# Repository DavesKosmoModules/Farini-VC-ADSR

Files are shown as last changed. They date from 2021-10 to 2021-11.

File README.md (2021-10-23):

# Farini-VC-ADSR

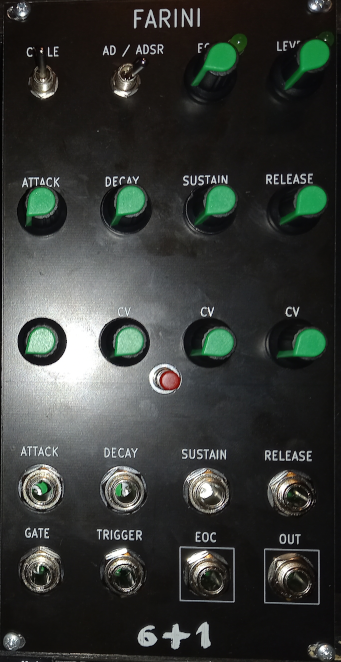
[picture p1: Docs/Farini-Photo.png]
Farini Photo


Voltage controlled AD / ADSR

- Envelope generator switchable between ADSR & AD
- Loopable
- End Of Cycle output
- Output can be inverted for ducking

- When in AD mode use the trigger input
- When in ADSR mode, use the gate input to start envelope, the trigger input will retigger the attach phase
- When in cycle mode use no inputs

 Contained are schematics & gerber files for pcb fabrication of both electrical and front panel. This is sutiable for entry level however a basic level of electronics, soldering, fault finding, and some basic tools are required.

 [Schematic](/Docs/Farini-Schematic.pdf)
 
 [BOM](Docs/Farini-BOM.pdf)

 If you wish to edit in ki-cad the following dependencies are required, however the component values will need tidying on the PCB as I use a forked version with no values.
 
  https://github.com/holmesrichards/Kosmo_panel
  
  https://github.com/holmesrichards/aoKicad

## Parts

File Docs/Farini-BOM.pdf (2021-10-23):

Id | Designator | Package | Quantity | Designation

1

| RV2,RV1,RV3,RV4,RV5,RV7,
| RV8,RV9,RV10 | Potentiometer_Alpha_RD901F‐40‐
| | 00D_Single_Vertical_CircularHoles_centered | | 9 100k

2

R45,R21,R3,R4,R5,R6,R8,R9
,R13,R14,R15,R16,R17,R18,
R19,R20,R22,R23,R26,R27,
R30,R31,R34,R37,R38,R39,
R41,R43,R46,R47,R48 | R_Axial_DIN0207_L6.3mm_D2.5mm_P10.16mm_Horizontal | 31 100k
3 R25,R32,R35 | R_Axial_DIN0207_L6.3mm_D2.5mm_P10.16mm_Horizontal | 3 10k
4 R1,R10,R11 | R_Axial_DIN0207_L6.3mm_D2.5mm_P10.16mm_Horizontal | 3 6k2
5 C1,C2 | CP_Radial_D6.3mm_P2.50mm | 2 10uF
6 C3,C4,C5,C6,C7,C8,C12,C13 C_Disc_D3.0mm_W1.6mm_P2.50mm | 8 0.1uF
7 C9 | C_Disc_D3.0mm_W1.6mm_P2.50mm | 1 0.001uF
8 C10 | C_Disc_D3.0mm_W1.6mm_P2.50mm | 1 0.01uF
9 C11 | C_Disc_D3.0mm_W1.6mm_P2.50mm | 1 0.03uF
10 D1,D5 | D_DO‐41_SOD81_P10.16mm_Horizontal | 2 1N5817

11

D2,D3,D4,D6,D7,D10,D11,D
12,D13 | D_DO‐35_SOD27_P7.62mm_Horizontal | 9 1N4148
12 D8,D9 | LED_D5.0mm | 2 LED
13 J1 | Power_Header | 1 Synth_power_2x5
14 J2 | PinHeader_1x10_P2.54mm_Vertical | 1 Conn_01x10_Male
15 Q1,Q2 | TO‐92_Inline_Wide | 2 2N3904
16 R2,R12,R24 | R_Axial_DIN0207_L6.3mm_D2.5mm_P10.16mm_Horizontal | 3 47k
17 R7,R33 | R_Axial_DIN0207_L6.3mm_D2.5mm_P10.16mm_Horizontal | 2 200k
18 R28,R42 | R_Axial_DIN0207_L6.3mm_D2.5mm_P10.16mm_Horizontal | 2 1k
19 R29 | R_Axial_DIN0207_L6.3mm_D2.5mm_P10.16mm_Horizontal | 1 30k
20 R36 | R_Axial_DIN0207_L6.3mm_D2.5mm_P10.16mm_Horizontal | 1 link
21 R40 | R_Axial_DIN0207_L6.3mm_D2.5mm_P10.16mm_Horizontal | 1 51k
22 R44 | R_Axial_DIN0207_L6.3mm_D2.5mm_P10.16mm_Horizontal | 1 470
23 RV6 | Potentiometer_Alpha_RD901F‐40‐
| 00D_Single_Vertical_CircularHoles_centered | 1 10k
24 SW1 | SPDT‐toggle‐switch‐1M‐series | 1 SW_SPDT
25 SW2 | DPDT‐toggle‐switch‐1M‐seriesx | 1 SW_DPDT_x2
26 SW3 | Push_button_A‐5050 | 1 SW_Push
27 U1,U2,U3 | DIP‐14_W7.62mm_Socket_LongPads | 3 TL074
28 U4 | DIP‐16_W7.62mm_Socket_LongPads | 1 AS3310
29 U5 | DIP‐8_W7.62mm_Socket_LongPads | 1 TL072

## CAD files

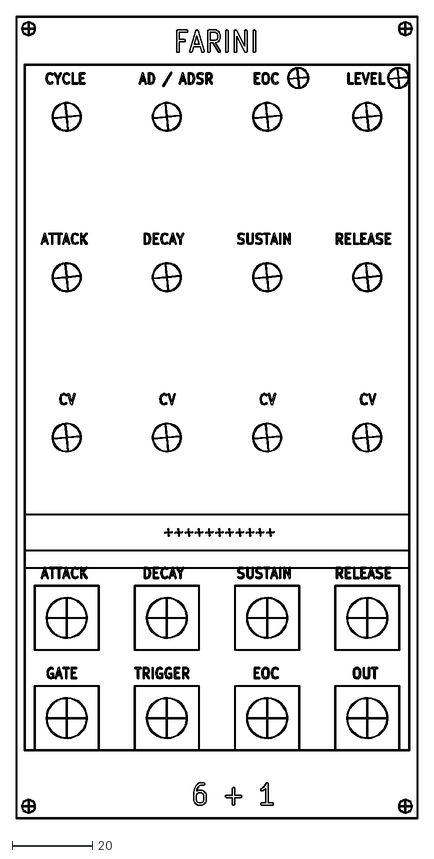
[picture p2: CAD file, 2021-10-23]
dwg/KOSMOS Function Generator-Dwgs_User.dxf
100.2 x 200.2

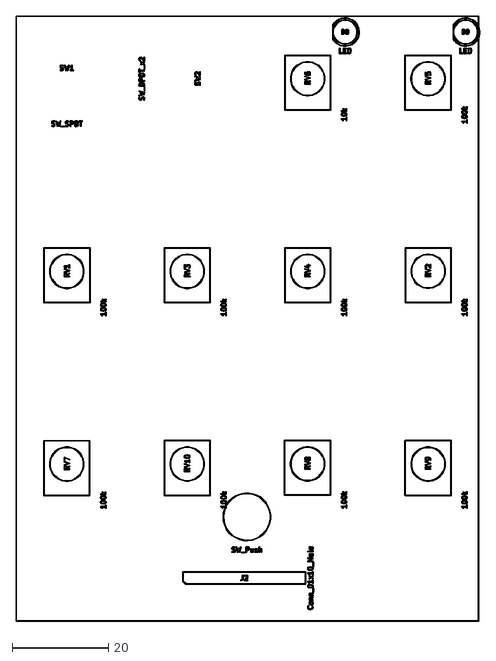
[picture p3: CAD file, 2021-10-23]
dwg/KOSMOS Function Generator-F_Fab.dxf
96.3 x 125.6

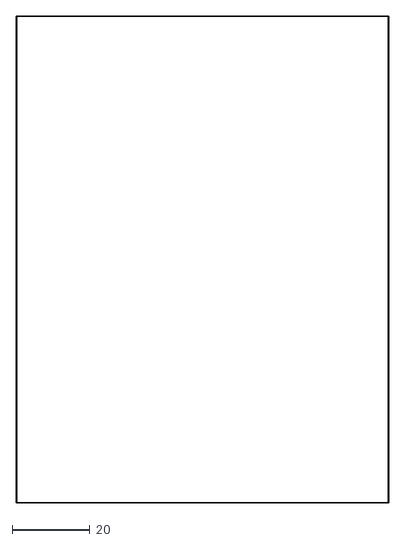
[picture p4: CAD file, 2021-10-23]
dwg/KOSMOS Function Generator-Cmts_User.dxf
96.0 x 125.6

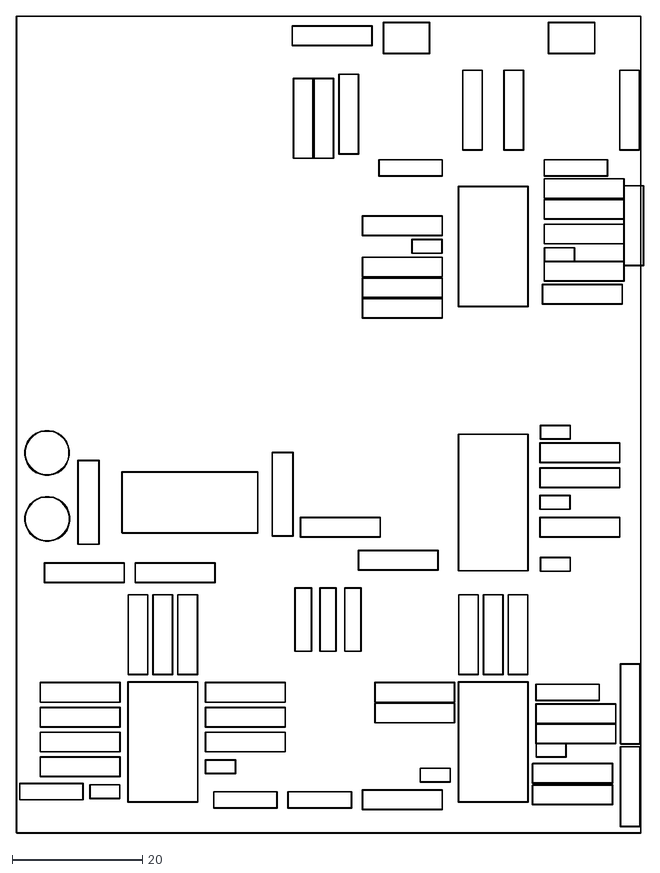
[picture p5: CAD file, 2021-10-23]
dwg/KOSMOS Function Generator-B_CrtYd.dxf
96.4 x 125.6

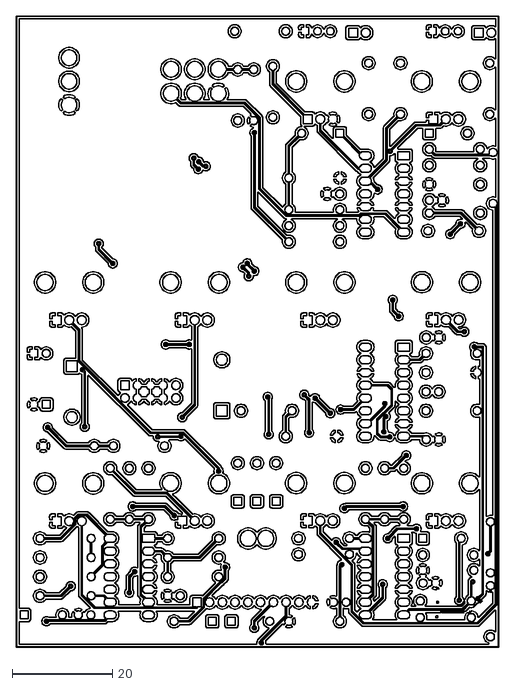
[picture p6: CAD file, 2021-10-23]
dwg/KOSMOS Function Generator-B_Cu.dxf
96.0 x 125.6

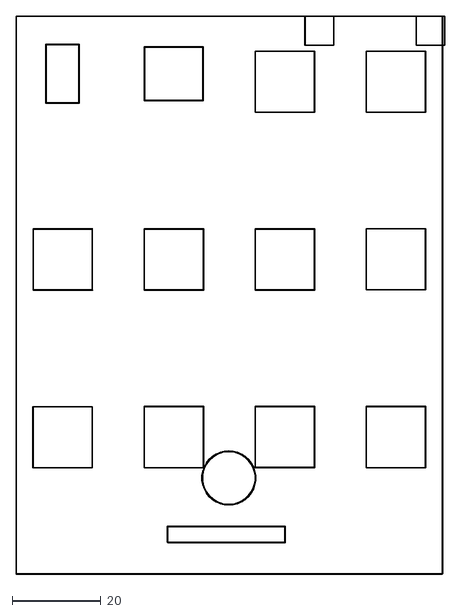
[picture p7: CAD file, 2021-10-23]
dwg/KOSMOS Function Generator-F_CrtYd.dxf
96.6 x 125.6

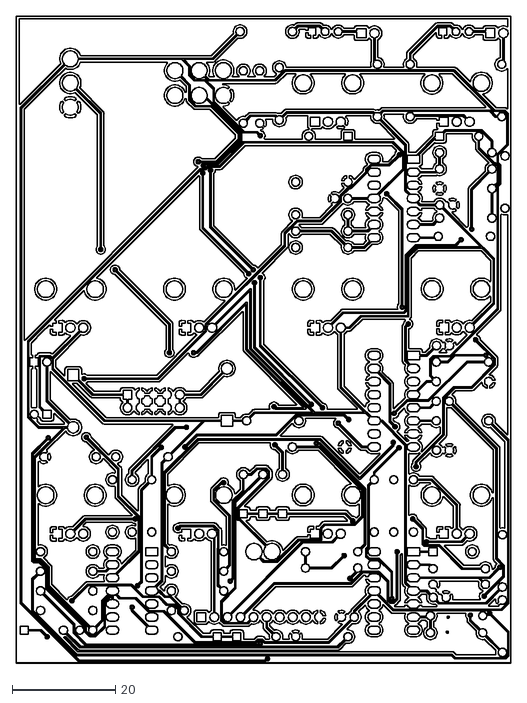
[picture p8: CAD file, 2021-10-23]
dwg/KOSMOS Function Generator-F_Cu.dxf
96.0 x 125.6

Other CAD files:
dwg/AdsrFontPanelExpoert.dxf
dwg/AdsrFrontPanel.dwg
dwg/KOSMOS Function Generator-B_Mask.dxf
dwg/KOSMOS Function Generator-B_SilkS.dxf
dwg/KOSMOS Function Generator-F_Mask.dxf
dwg/KOSMOS Function Generator-F_SilkS.dxf

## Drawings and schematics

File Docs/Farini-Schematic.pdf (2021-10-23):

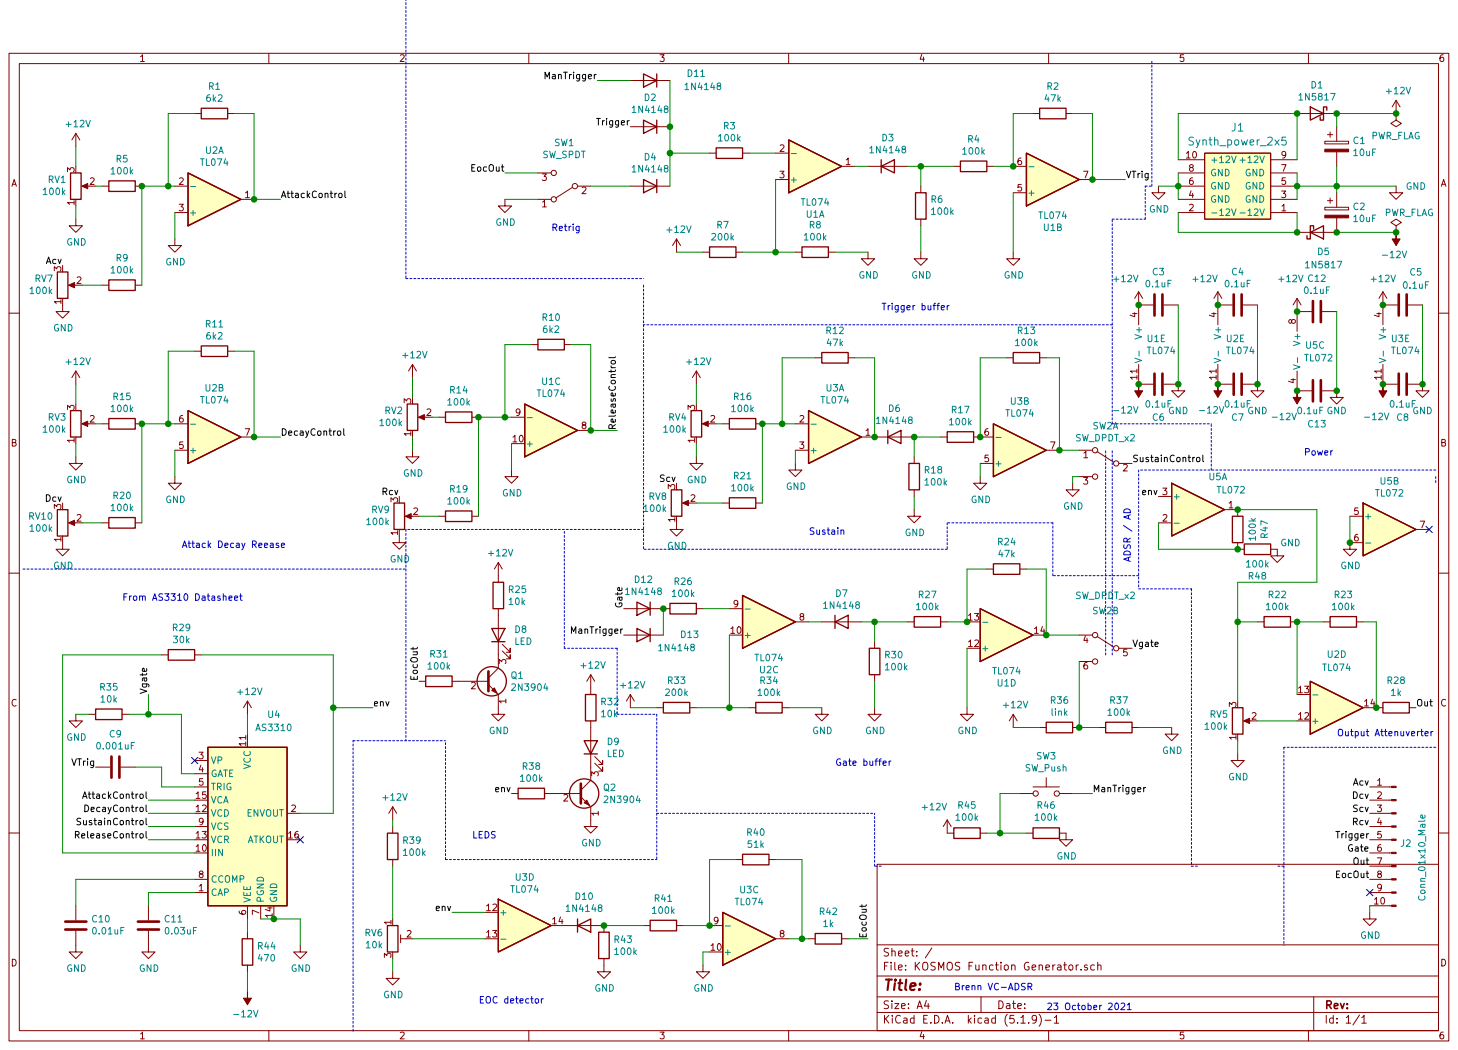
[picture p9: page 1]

Sustain Attack Decay Reease

Id: 1/1 Title: File: KOSMOS Function Generator.sch Sheet: / R33

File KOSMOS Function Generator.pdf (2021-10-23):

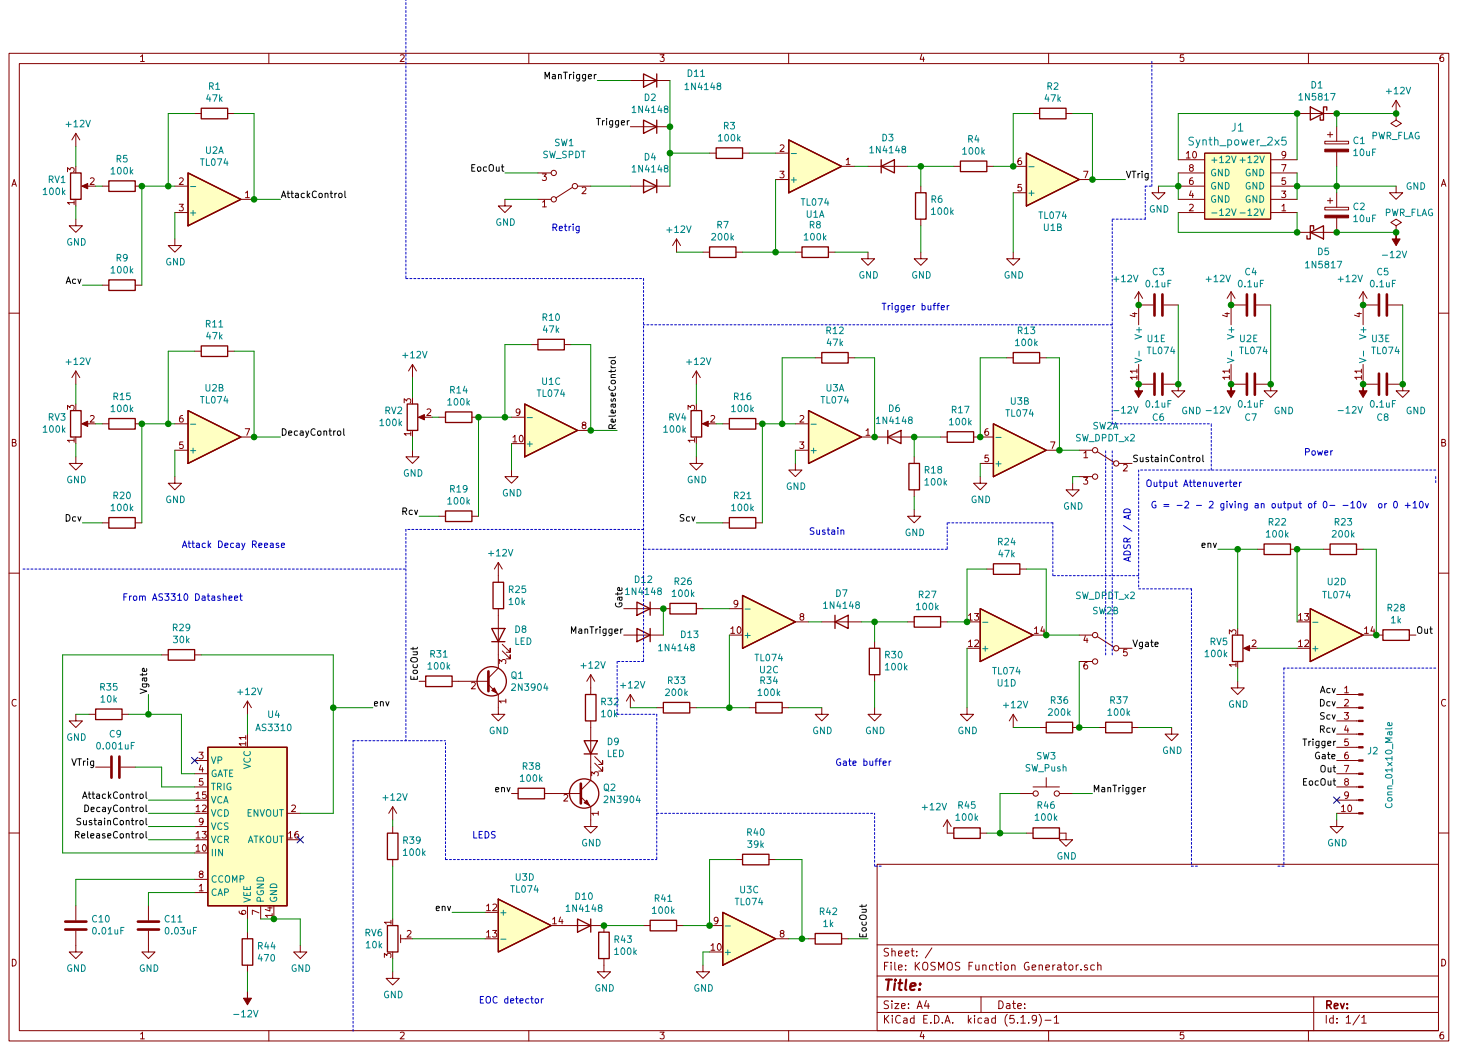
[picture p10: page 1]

Trigger buffer Sustain Attack Decay Reease

Trigger Gate Rcv Output Attenuverter

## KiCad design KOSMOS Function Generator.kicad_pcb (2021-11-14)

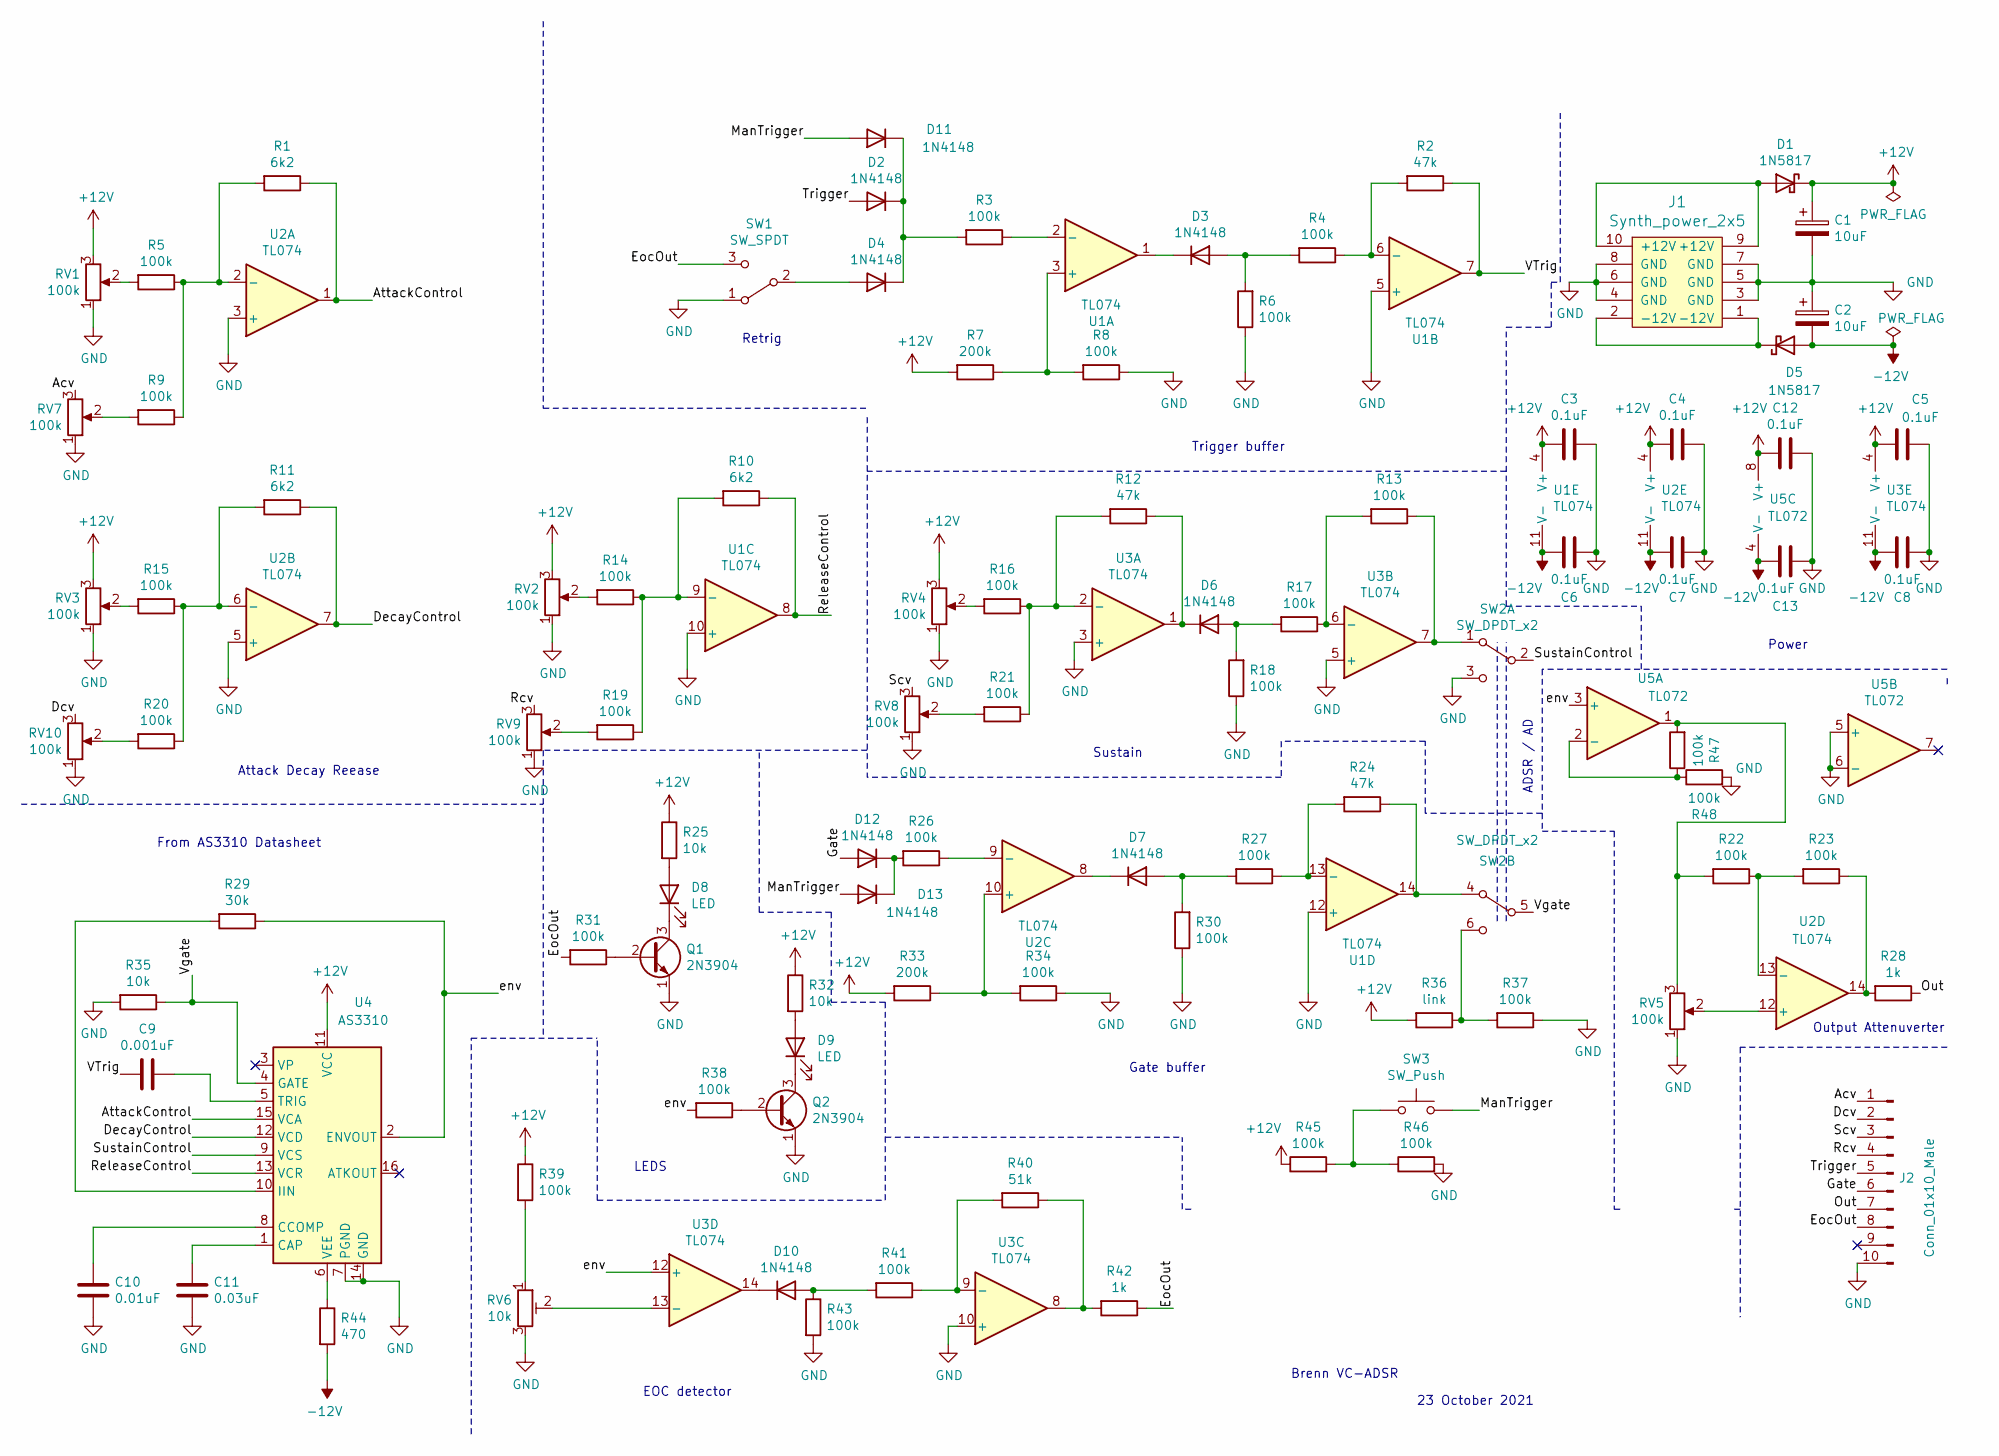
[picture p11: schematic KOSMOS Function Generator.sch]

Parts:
C1, C2: 10uF; CP_Radial_D6.3mm_P2.50mm
C3, C4, C5, C6, C7, C8, C12, C13: 0.1uF; C_Disc_D3.0mm_W1.6mm_P2.50mm
C9: 0.001uF; C_Disc_D3.0mm_W1.6mm_P2.50mm
C10: 0.01uF; C_Disc_D3.0mm_W1.6mm_P2.50mm
C11: 0.03uF; C_Disc_D3.0mm_W1.6mm_P2.50mm
D1, D5: 1N5817; D_DO-41_SOD81_P10.16mm_Horizontal
D2, D3, D4, D6, D7, D10, D11, D12, D13: 1N4148; D_DO-35_SOD27_P7.62mm_Horizontal
D8, D9: LED; LED_D5.0mm
J1: Synth_power_2x5; Power_Header
J2: Conn_01x10_Male; PinHeader_1x10_P2.54mm_Vertical
Q1, Q2: 2N3904; TO-92_Inline_Wide
R1, R10, R11: 6k2; R_Axial_DIN0207_L6.3mm_D2.5mm_P10.16mm_Horizontal
R2, R12, R24: 47k; R_Axial_DIN0207_L6.3mm_D2.5mm_P10.16mm_Horizontal
R3, R4, R5, R6, R8, R9, R13, R14, R15, R16, R17, R18, R19, R20, R21, R22, R23, R26, R27, R30, R31, R34, R37, R38, R39, R41, R43, R45, R46, R47, R48: 100k; R_Axial_DIN0207_L6.3mm_D2.5mm_P10.16mm_Horizontal
R7, R33: 200k; R_Axial_DIN0207_L6.3mm_D2.5mm_P10.16mm_Horizontal
R25, R32, R35: 10k; R_Axial_DIN0207_L6.3mm_D2.5mm_P10.16mm_Horizontal
R28, R42: 1k; R_Axial_DIN0207_L6.3mm_D2.5mm_P10.16mm_Horizontal
R29: 30k; R_Axial_DIN0207_L6.3mm_D2.5mm_P10.16mm_Horizontal
R36: link; R_Axial_DIN0207_L6.3mm_D2.5mm_P10.16mm_Horizontal
R40: 51k; R_Axial_DIN0207_L6.3mm_D2.5mm_P10.16mm_Horizontal
R44: 470; R_Axial_DIN0207_L6.3mm_D2.5mm_P10.16mm_Horizontal
RV1, RV2, RV3, RV4, RV5, RV7, RV8, RV9, RV10: 100k; Potentiometer_Alpha_RD901F-40-00D_Single_Vertical_CircularH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
RV6: 10k; Potentiometer_Alpha_RD901F-40-00D_Single_Vertical_CircularH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
SW1: SW_SPDT; SPDT-toggle-switch-1M-series
SW2: SW_DPDT_x2; DPDT-toggle-switch-1M-seriesx
SW3: SW_Push; Push_button_A-5050
U1, U2, U3: TL074; DIP-14_W7.62mm_Socket_LongPads
U4: AS3310; DIP-16_W7.62mm_Socket_LongPads
U5: TL072; DIP-8_W7.62mm_Socket_LongPads

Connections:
+12V: C1.1, C3.2, C4.2, C5.2, C12.2, D1.1 (K), R7.2, R25.1, R32.1, R33.2, R36.2, R39.1, R45.1, RV1.3, RV2.3, RV3.3, RV4.3, U1.4 (V+), U2.4 (V+), U3.4 (V+), U4.11 (VCC), U5.8 (V+)
-12V: C2.2, C6.2, C7.2, C8.2, C13.2, D5.2 (A), R44.2, U1.11 (V-), U2.11 (V-), U3.11 (V-), U5.4 (V-)
/Acv: J2.1, RV7.3
/AttackControl: R1.1, U2.1, U4.15 (VCA)
/Dcv: J2.2, RV10.3
/DecayControl: R11.1, U2.7, U4.12 (VCD)
/EocOut: J2.8, R31.2, R42.1, SW1.3 (C)
/Gate: D12.2 (A), J2.6
/ManTrigger: D11.2 (A), D13.2 (A), SW3.2
/Out: J2.7, R28.1
/Rcv: J2.4, RV9.3
/ReleaseControl: R10.1, U1.8, U4.13 (VCR)
/Scv: J2.3, RV8.3
/SustainControl: SW2.2 (B), U4.9 (VCS)
/Trigger: D2.2 (A), J2.5
/VTrig: C9.2, R2.1, U1.7
/Vgate: R35.1, SW2.5 (B), U4.4 (GATE)
/env: R29.1, R38.2, U3.12 (+), U4.2 (ENVOUT), U5.3 (+)
GND: C1.2, C2.1, C3.1, C4.1, C5.1, C6.1, C7.1, C8.1, C10.1, C11.1, C12.1, C13.1, J1.3 (GND), J1.4 (GND), J1.5 (GND), J1.6 (GND), J1.7 (GND), J1.8 (GND), J2.10, Q1.1 (E), Q2.1 (E), R6.1, R8.1, R18.1, R30.1, R34.1, R35.2, R37.1, R43.2, R46.2, R48.2, RV1.1, RV2.1, RV3.1, RV4.1, RV5.1, RV6.3, RV7.1, RV8.1, RV9.1, RV10.1, SW1.1 (A), SW2.3 (C), U1.5 (+), U1.10 (+), U1.12 (+), U2.3 (+), U2.5 (+), U3.3 (+), U3.5 (+), U3.10 (+), U4.7 (PGND), U4.14 (GND), U5.5 (+), U5.6 (-)
unnamed: C9.1, U4.5 (TRIG)
unnamed: C10.2, U4.8 (CCOMP)
unnamed: C11.2, U4.1 (CAP)
unnamed: D1.2 (A), J1.9 (+12V), J1.10 (+12V)
unnamed: D3.1 (K), U1.1
unnamed: D3.2 (A), R4.2, R6.2
unnamed: D4.2 (A), SW1.2 (B)
unnamed: D5.1 (K), J1.1 (-12V), J1.2 (-12V)
unnamed: D6.1 (K), R12.1, U3.1
unnamed: D6.2 (A), R17.2, R18.2
unnamed: D7.1 (K), U2.8
unnamed: D7.2 (A), R27.2, R30.2
unnamed: D8.1 (K), Q1.3 (C)
unnamed: D8.2 (A), R25.2
unnamed: D9.1 (K), Q2.3 (C)
unnamed: D9.2 (A), R32.2
unnamed: D10.1 (K), U3.14
unnamed: D10.2 (A), R41.2, R43.1
unnamed: D2.1 (K), D4.1 (K), D11.1 (K), R3.2
unnamed: D12.1 (K), D13.1 (K), R26.2
unnamed: Q1.2 (B), R31.1
unnamed: Q2.2 (B), R38.1
unnamed: R1.2, R5.1, R9.1, U2.2 (-)
unnamed: R2.2, R4.1, U1.6 (-)
unnamed: R3.1, U1.2 (-)
unnamed: R5.2, RV1.2
unnamed: R7.1, R8.2, U1.3 (+)
unnamed: R9.2, RV7.2
unnamed: R10.2, R14.1, R19.1, U1.9 (-)
unnamed: R11.2, R15.1, R20.1, U2.6 (-)
unnamed: R12.2, R16.1, R21.1, U3.2 (-)
unnamed: R13.1, SW2.1 (A), U3.7
unnamed: R13.2, R17.1, U3.6 (-)
unnamed: R14.2, RV2.2
unnamed: R15.2, RV3.2
unnamed: R16.2, RV4.2
unnamed: R19.2, RV9.2
unnamed: R20.2, RV10.2
unnamed: R21.2, RV8.2
unnamed: R22.1, R23.2, U2.13 (-)
unnamed: R22.2, R47.2, RV5.3, U5.1
unnamed: R23.1, R28.2, U2.14
unnamed: R24.1, SW2.4 (A), U1.14
unnamed: R24.2, R27.1, U1.13 (-)
unnamed: R26.1, U2.9 (-)
unnamed: R29.2, U4.10 (IIN)
unnamed: R33.1, R34.2, U2.10 (+)
unnamed: R36.1, R37.2, SW2.6 (C)
unnamed: R39.2, RV6.1
unnamed: R40.1, R42.2, U3.8
unnamed: R40.2, R41.1, U3.9 (-)
unnamed: R44.1, U4.6 (VEE)
unnamed: R45.2, R46.1, SW3.1
unnamed: R47.1, R48.1, U5.2 (-)
unnamed: RV5.2, U2.12 (+)
unnamed: RV6.2, U3.13 (-)

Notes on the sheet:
Output Attenuverter
Trigger buffer
Gate buffer
Retrig
ADSR / AD
From AS3310 Datasheet
LEDS
EOC detector
Sustain
Power
Attack Decay Reease
Brenn VC-ADSR
23 October 2021

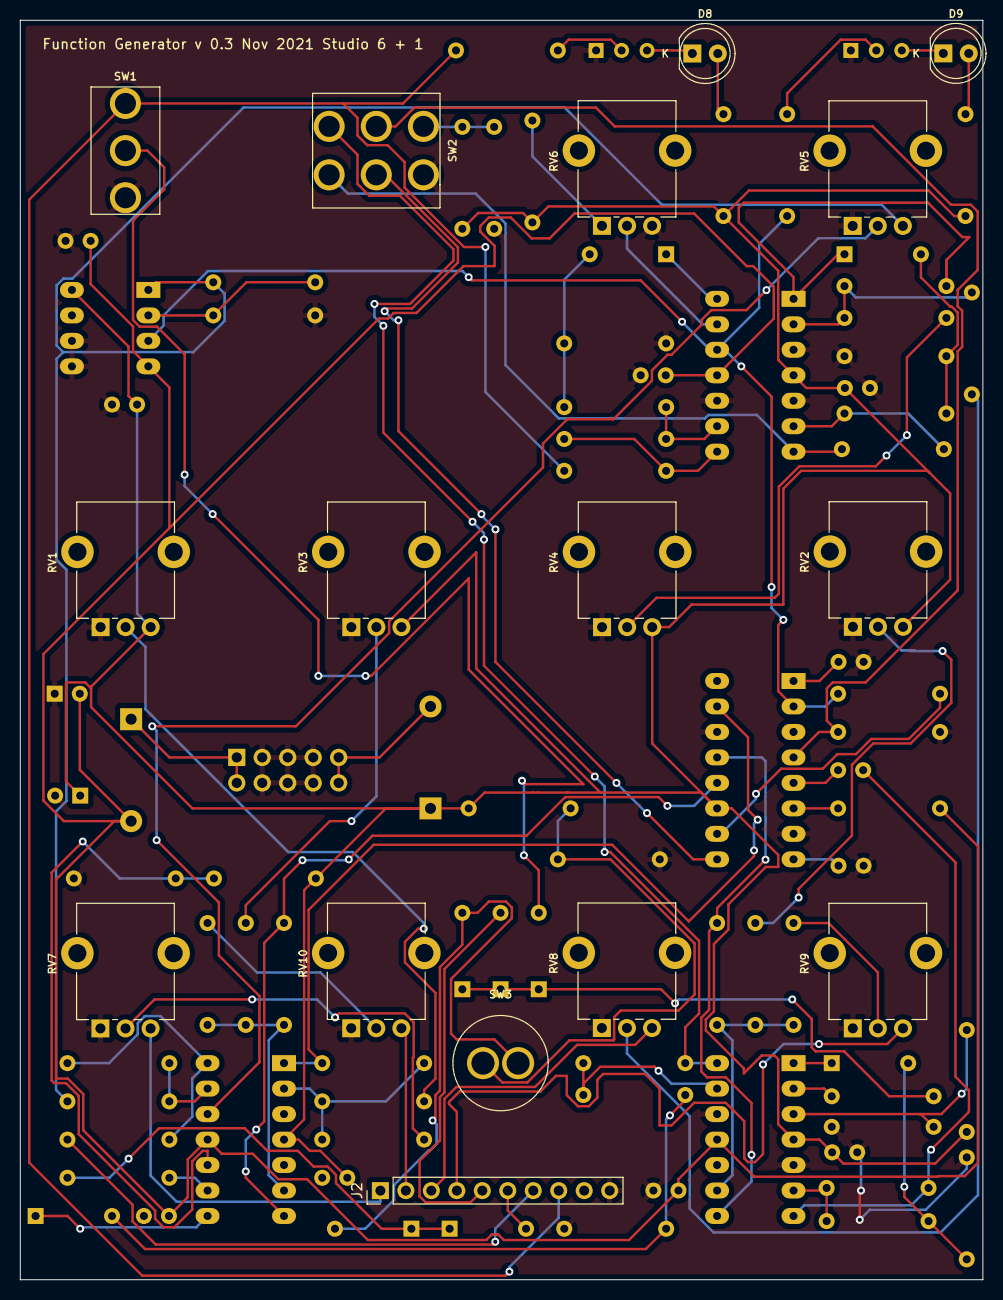
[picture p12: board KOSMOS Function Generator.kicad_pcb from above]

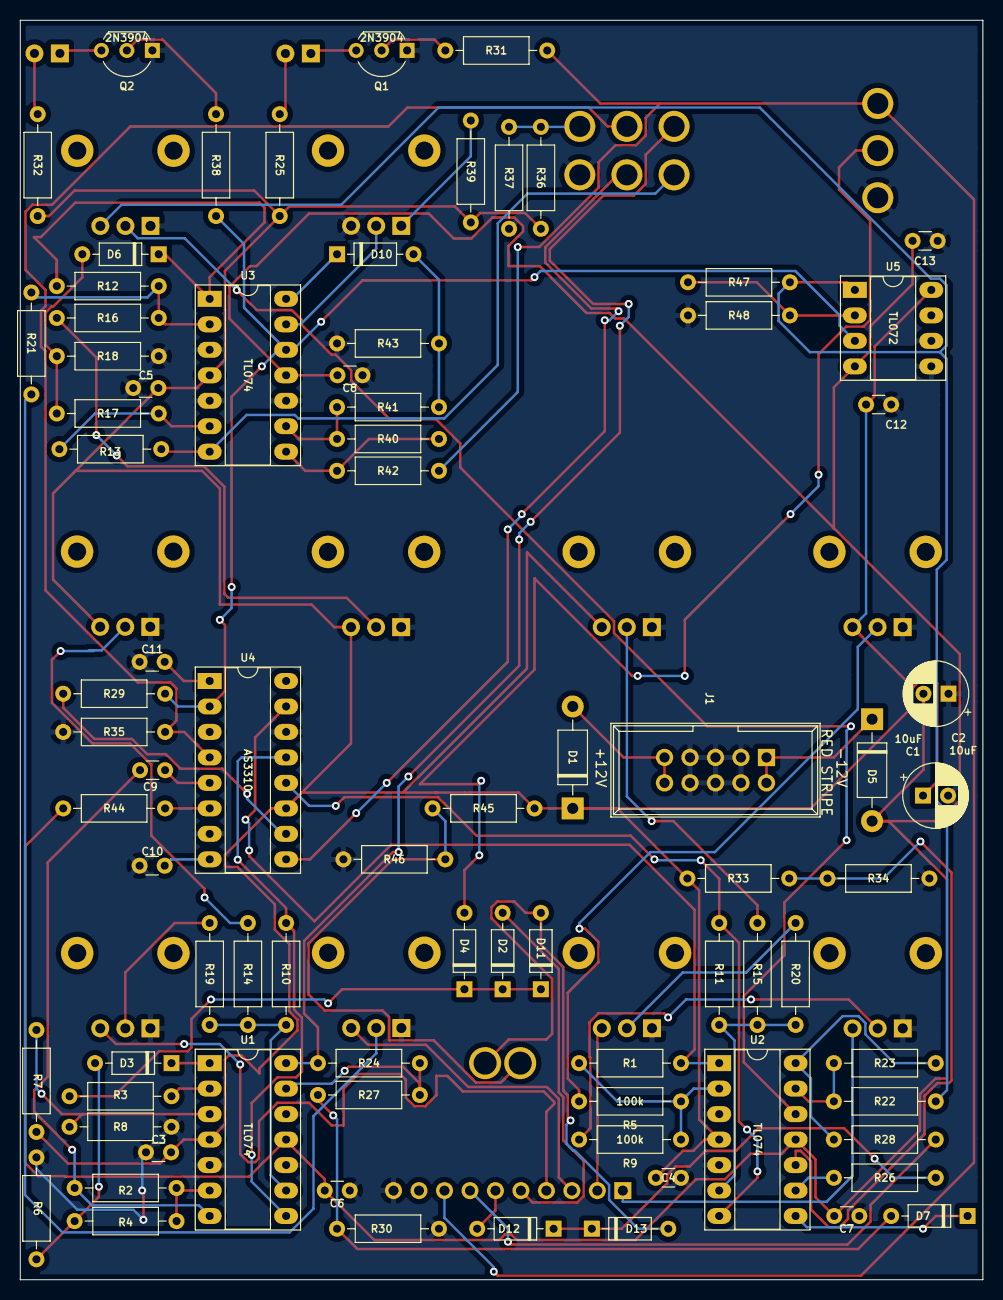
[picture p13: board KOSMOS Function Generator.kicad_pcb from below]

Board: 2 copper layers, 96.0 x 125.6 mm, 96 parts (80 on the bottom side), 75 nets.

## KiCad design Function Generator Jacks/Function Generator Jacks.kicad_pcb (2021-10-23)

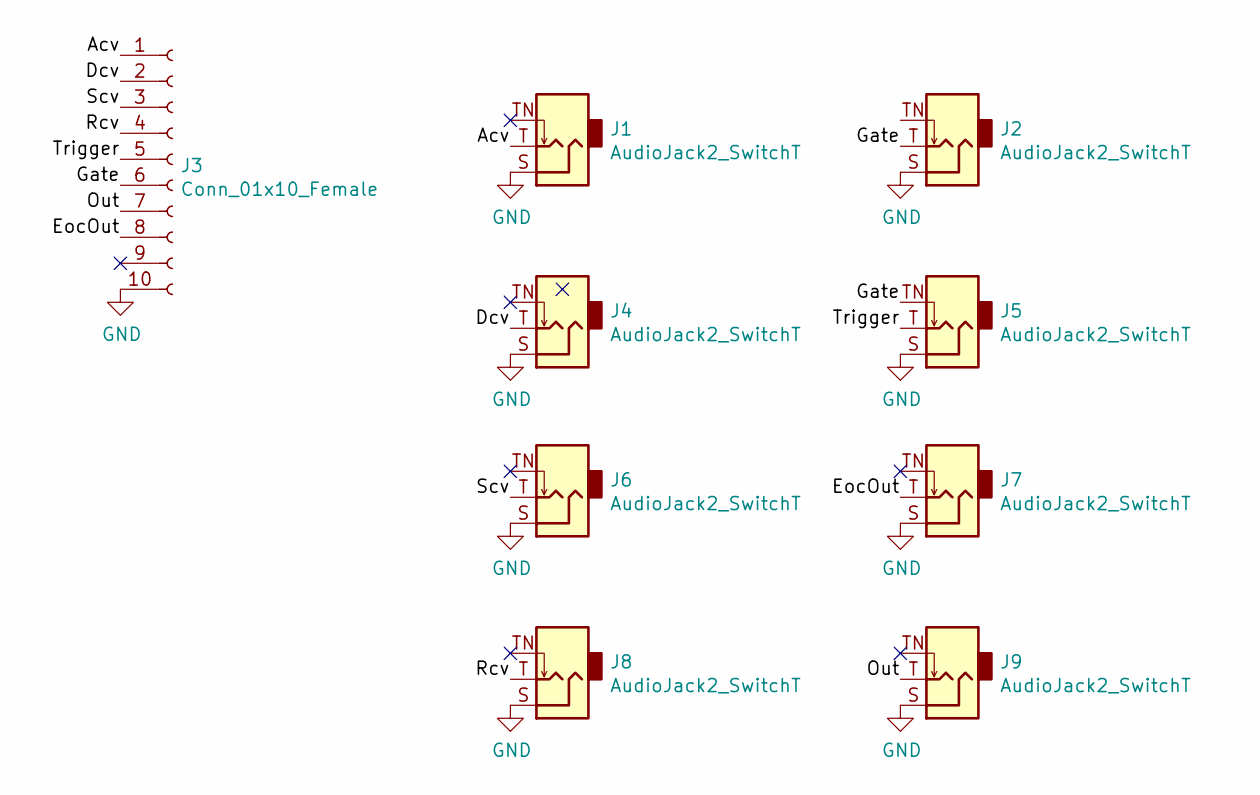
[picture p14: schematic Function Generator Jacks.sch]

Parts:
J1, J2, J4, J5, J6, J7, J8, J9: AudioJack2_SwitchT; Jack_6.35mm_PJ_629HAN
J3: Conn_01x10_Female; PinSocket_1x10_P2.54mm_Vertical

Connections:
/Acv: J1.T, J3.1
/Dcv: J3.2, J4.T
/EocOut: J3.8, J7.T
/Gate: J2.T, J3.6, J5.TN
/Out: J3.7, J9.T
/Rcv: J3.4, J8.T
/Scv: J3.3, J6.T
/Trigger: J3.5, J5.T
GND: J1.S, J2.S, J3.10, J4.S, J5.S, J6.S, J7.S, J8.S, J9.S

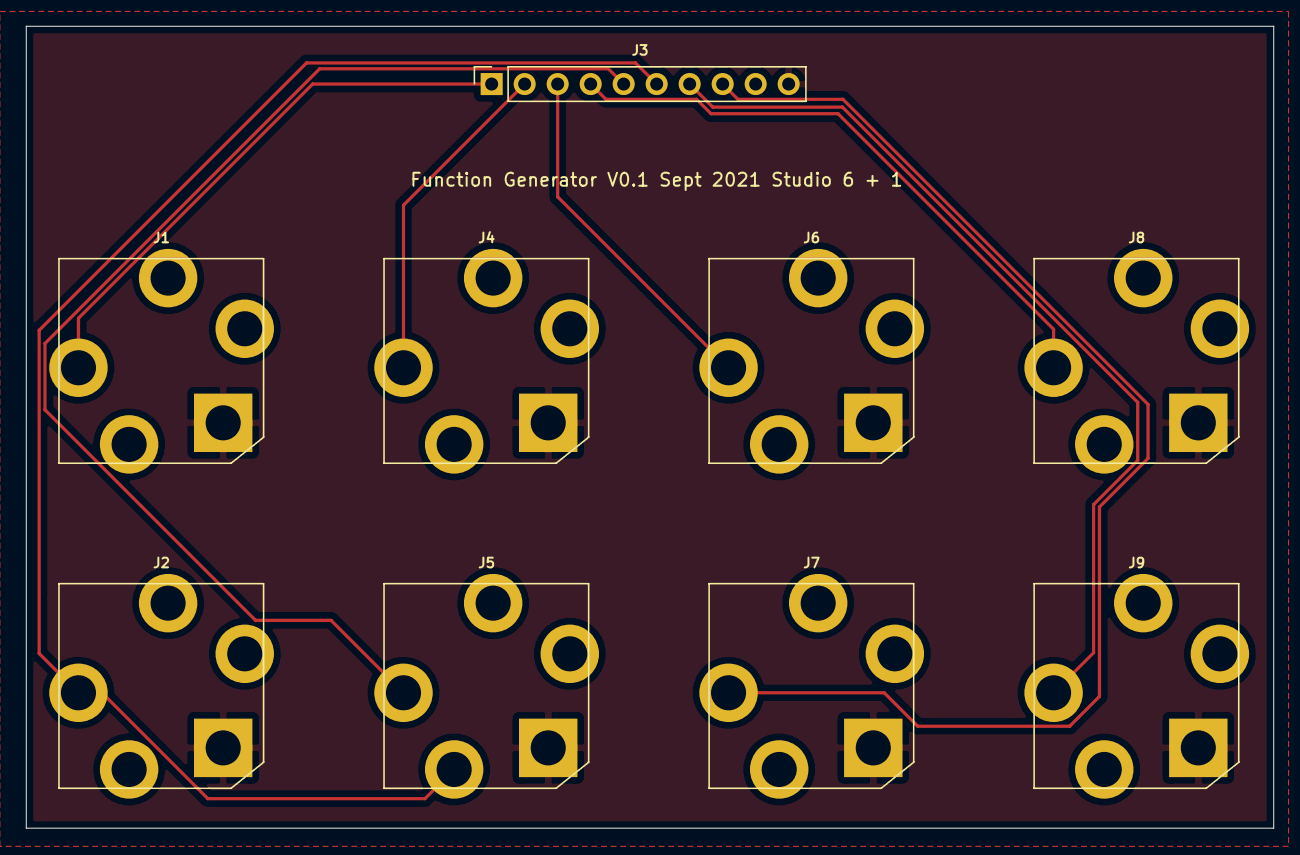
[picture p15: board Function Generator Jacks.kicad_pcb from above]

Board: 2 copper layers, 96.0 x 61.7 mm, 9 parts (0 on the bottom side), 9 nets.

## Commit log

2021-11-13 v03 pcb connect ground plane region
    [KOSMOS Function Generator-B_Adhes.gbr, KOSMOS Function Generator-B_CrtYd.gbr, KOSMOS Function Generator-B_Cu.gbr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]
2021-11-14 pcb v03
    [KOSMOS Function Generator.kicad_pcb]
